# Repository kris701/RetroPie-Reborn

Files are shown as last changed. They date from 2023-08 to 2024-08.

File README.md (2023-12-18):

# RetroPie-Reborn
This is a project to make a handheld console, that can run games from around PlayStation 1 and down.




Its basically a Raspberry Pi 4 that runs on RetroPie. It has small icons that show up in the corner, to give info in things such as how much battery is left or if the Pi is connected to Wifi.
Hardware wise, it has a 7' LCD screen, two small speakers, AUX output, USB-A output and USB-C charging port.
It has two 5000mAh batteries inside of it, giving it ~4 hours of normal usage before running out (but it really depends on what you use it for).
The console also has a little fan, that automatically turns on and off depending on the internal temperature of the Pi.

I originally designed it to include build in controllers on the side, however making the PCBs for the button pads didnt work out.
As a backup, i build in a connector on the two sides of the console, that can be used for future controller additions. 
Each side is basically mirrored, pinout wise, where each side supports up to 11 buttons (or 9 buttons and 2 analog inputs). Each side also have a GND and +5V pin.

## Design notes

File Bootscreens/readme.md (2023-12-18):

# Bootscreens

A custom bootscreen for RetroPie was also made, using Adobe After Effects (the `.aep` file is located here)
There is one thats an entire minute, and one that have been cut to somewhat fit the boot time it took for the Pi i used.

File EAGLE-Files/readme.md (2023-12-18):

# EAGLE Files

I made a bunch of custom PCB components for this project.
In this folder is all the EAGLE sketch and board files for it.
I milled all the boards on my CNC machine.

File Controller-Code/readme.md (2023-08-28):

Based on https://github.com/alexis-boisserand/RetroDeluxe-TeensyController

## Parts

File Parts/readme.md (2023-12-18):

# Parts used

* Raspberry Pi 4B 8GB
* SanDisk Extreme PRo 128GB SD Card
* Micro-HDMI to HDMI: 
* Type-C USB charger board for 2S: 
* 2x 5000mah LiPo Battery: 
* 7-inch LCD Screen: 
* USB Extender: 
* 3.5mm AUX Socket: 
* Raspberry Pi 4B Heatsinks: 
* 2S to 5v, 5A, Step Down: 
* ADS1015: 
* 5v Fan: 
* PAM8403: 
* 8 Ohm Speaker:

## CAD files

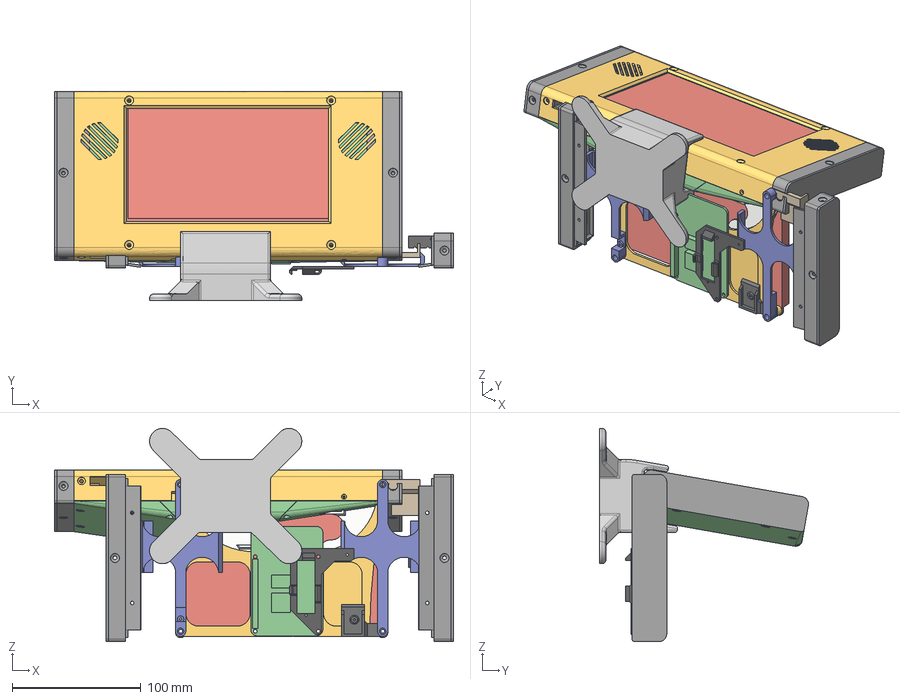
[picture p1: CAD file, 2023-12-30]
3D-Print-Files/Stand.iges
310.0 x 162.4 x 165.6 mm

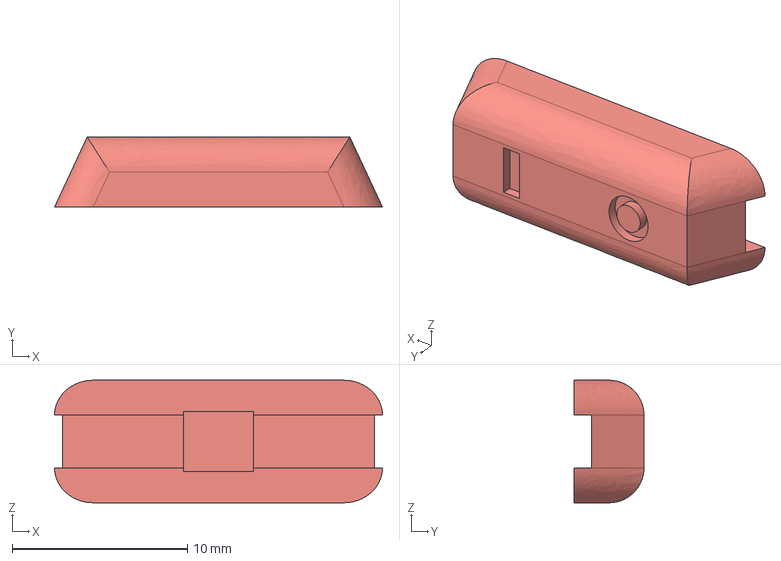
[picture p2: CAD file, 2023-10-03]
3D-Print-Files/SwitchCover.iges
18.7 x 4.00 x 7.00 mm

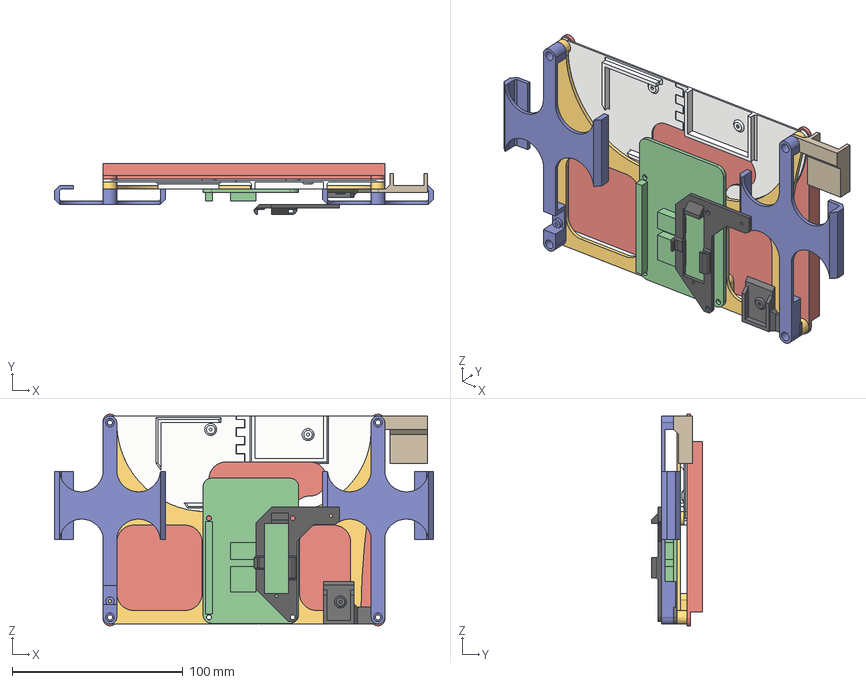
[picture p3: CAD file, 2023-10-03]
3D-Print-Files/Bracket.iges
222.0 x 30.0 x 124.0 mm

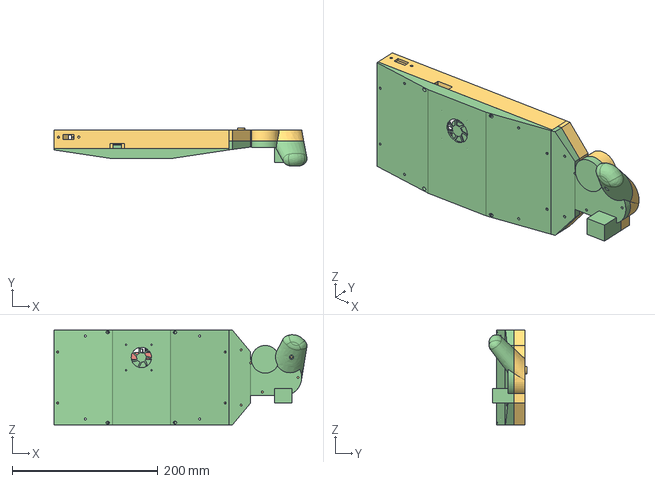
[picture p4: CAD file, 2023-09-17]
3D-Print-Files/Shell.iges
347.3 x 52.0 x 130.0 mm

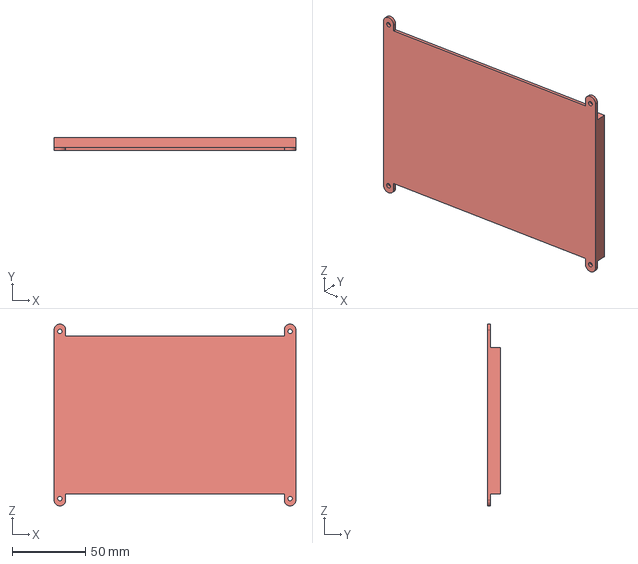
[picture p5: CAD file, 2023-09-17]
3D-Print-Files/Screen.iges
165.0 x 9.00 x 124.0 mm

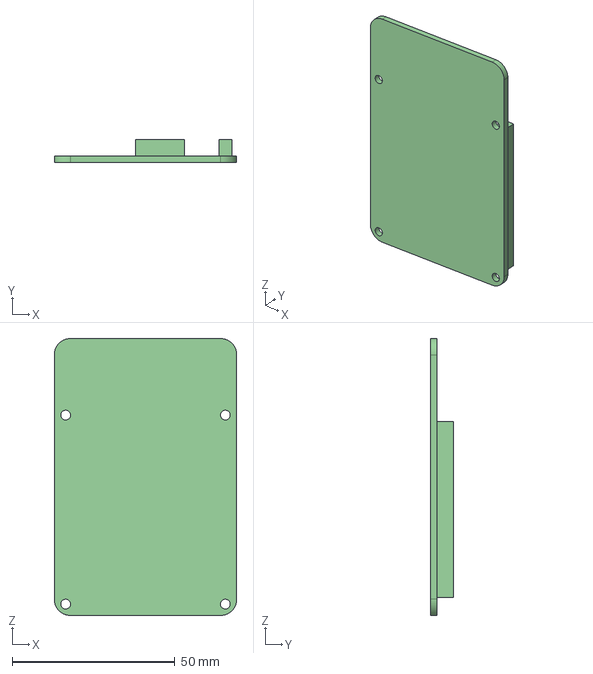
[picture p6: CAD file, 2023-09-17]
3D-Print-Files/Raspberry Pi 4.iges
56.0 x 7.00 x 85.0 mm

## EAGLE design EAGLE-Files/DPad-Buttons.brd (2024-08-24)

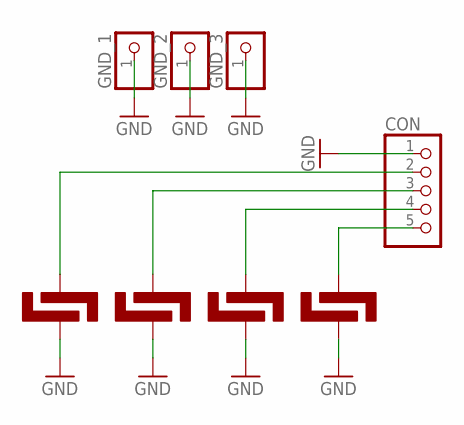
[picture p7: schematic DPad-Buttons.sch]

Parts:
BTN1, BTN2, BTN3, BTN4: BTN_5MM_LONG
CON: PINHD-1X5/90; 1X05/90
GND_1, GND_2, GND_3: PINHD-1X1; 1X01

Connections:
GND: BTN1.P$2, BTN2.P$2, BTN3.P$2, BTN4.P$2, CON.1, GND_1.1, GND_2.1, GND_3.1
unnamed: BTN1.P$1, CON.2
unnamed: BTN4.P$1, CON.5
unnamed: BTN3.P$1, CON.4
unnamed: BTN2.P$1, CON.3

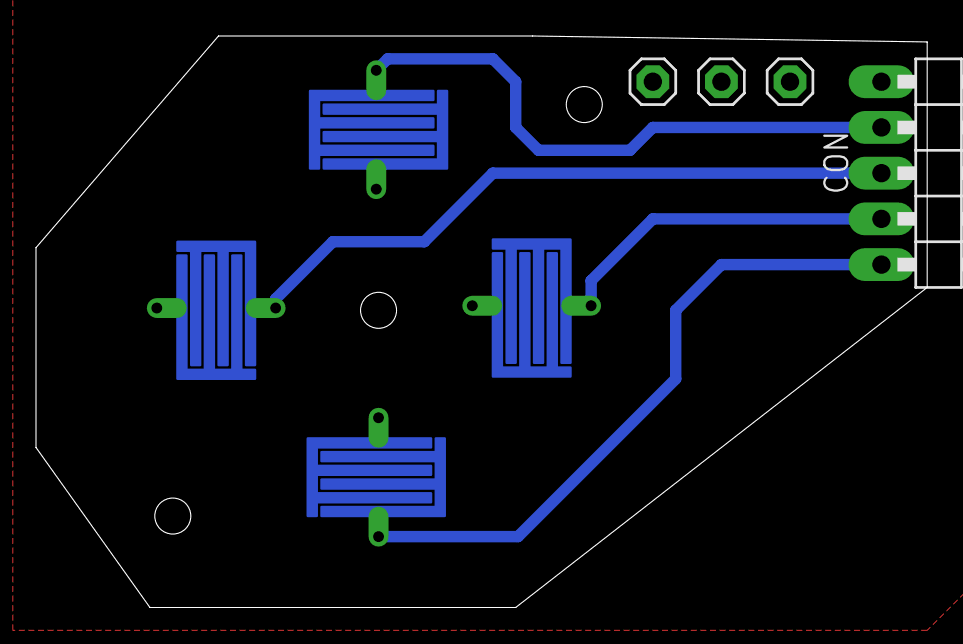
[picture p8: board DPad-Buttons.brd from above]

Board: 2 copper layers, 49.5 x 31.8 mm, 8 parts (0 on the bottom side), 5 nets.

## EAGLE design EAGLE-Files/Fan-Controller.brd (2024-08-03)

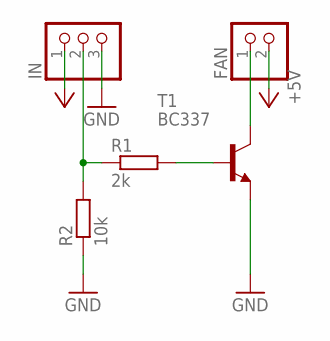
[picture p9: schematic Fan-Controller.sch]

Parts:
FAN: PINHD-1X2/90; 1X02/90
IN: PINHD-1X3/90; 1X03/90
R1: 2k; 0204/7
R2: 10k; 0204/7
T1: BC337; TO92

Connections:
+5V: FAN.2, IN.1
GND: IN.3, R2.1, T1.1 (E)
unnamed: FAN.1, T1.3 (C)
unnamed: R1.2, T1.2 (B)
unnamed: IN.2, R1.1, R2.2

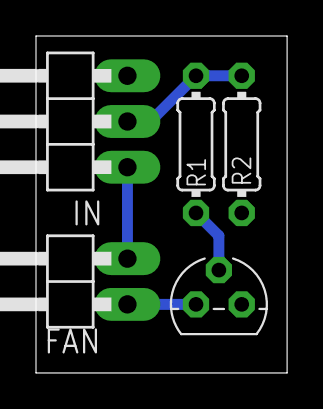
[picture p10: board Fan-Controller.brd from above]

Board: 2 copper layers, 13.9 x 18.7 mm, 5 parts (0 on the bottom side), 5 nets.

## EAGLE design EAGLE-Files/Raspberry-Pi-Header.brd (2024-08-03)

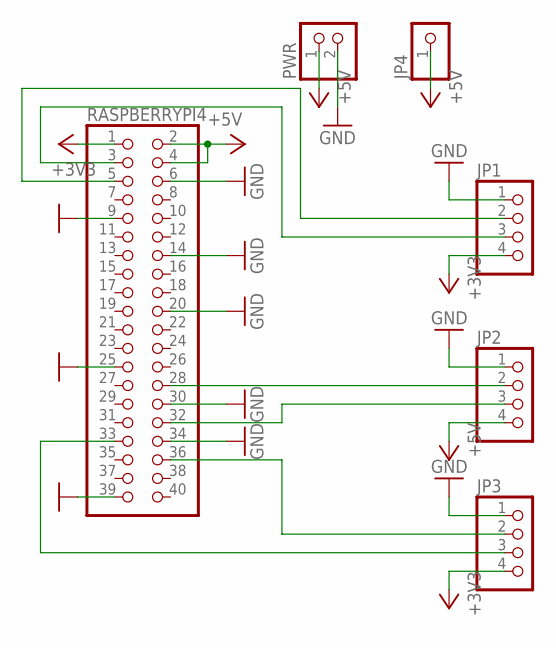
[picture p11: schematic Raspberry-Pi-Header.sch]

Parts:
JP1, JP2, JP3: PINHD-1X4/90; 1X04/90
JP4: PINHD-1X1; 1X01
PWR: PINHD-1X2/90; 1X02/90
RASPBERRYPI4: PINHD-2X20; 2X20

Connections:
+3V3: JP1.4, JP3.4, RASPBERRYPI4.1
+5V: JP2.4, JP4.1, PWR.1, RASPBERRYPI4.2, RASPBERRYPI4.4
GND: JP1.1, JP2.1, JP3.1, PWR.2, RASPBERRYPI4.6, RASPBERRYPI4.9, RASPBERRYPI4.14, RASPBERRYPI4.20, RASPBERRYPI4.25, RASPBERRYPI4.30, RASPBERRYPI4.34, RASPBERRYPI4.39
GPIO1: JP2.2, RASPBERRYPI4.28
GPIO12: JP2.3, RASPBERRYPI4.32
GPIO13: JP3.3, RASPBERRYPI4.33
GPIO16: JP3.2, RASPBERRYPI4.36
SCL: JP1.2, RASPBERRYPI4.5
SDA: JP1.3, RASPBERRYPI4.3

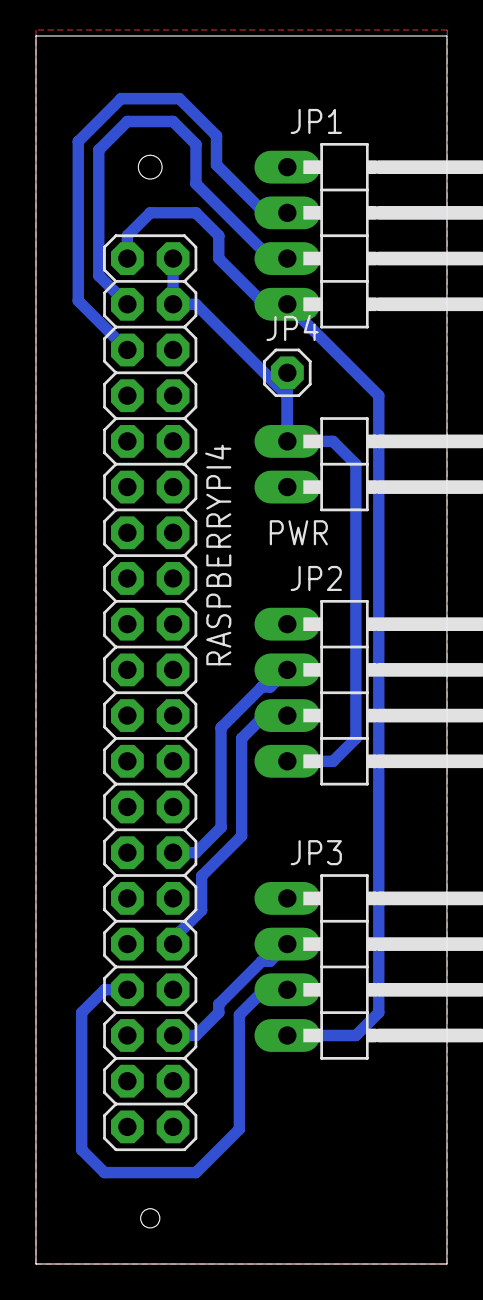
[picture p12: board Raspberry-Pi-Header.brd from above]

Board: 2 copper layers, 22.8 x 68.2 mm, 6 parts (0 on the bottom side), 9 nets.

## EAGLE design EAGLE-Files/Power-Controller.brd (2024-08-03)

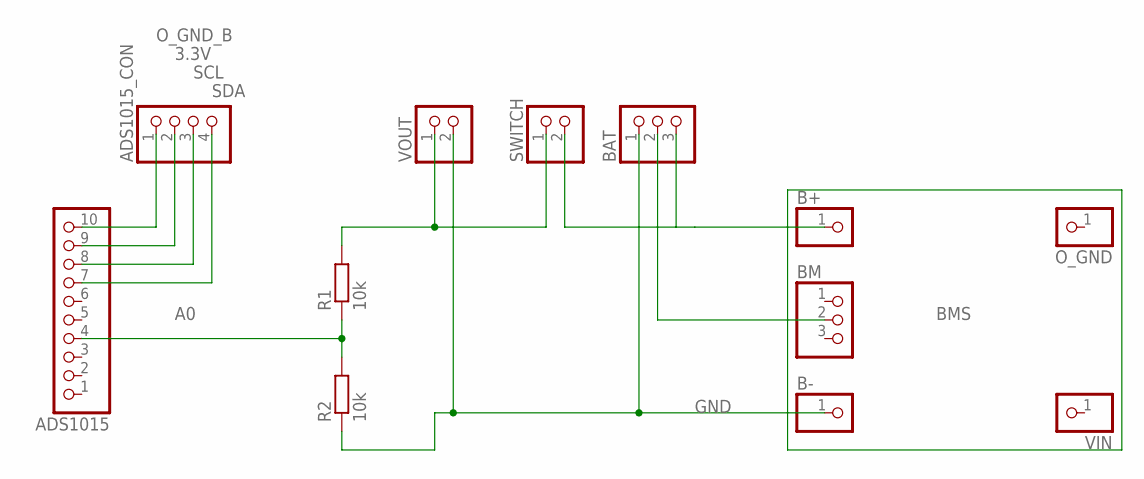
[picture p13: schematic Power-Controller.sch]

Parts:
ADS1015: PINHD-1X10; 1X10
ADS1015_CON: PINHD-1X4/90; 1X04/90
B+: PINHD-1X1; 1X01
B-: PINHD-1X1; 1X01
BAT: PINHD-1X3/90; 1X03/90
BM: PINHD-1X3; 1X03
O_GND: PINHD-1X1; 1X01
R1, R2: 10k; 0204/7
SWITCH: PINHD-1X2; 1X02
VIN: PINHD-1X1; 1X01
VOUT: PINHD-1X2/90; 1X02/90

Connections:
3.3V: ADS1015.9, ADS1015_CON.2
A0: ADS1015.4, R1.1, R2.2
GND: B-.1, BAT.1, R2.1, VOUT.2
unnamed: B+.1, BAT.3, SWITCH.2
unnamed: BAT.2, BM.2
unnamed: R1.2, SWITCH.1, VOUT.1
O_GND_B: ADS1015.10, ADS1015_CON.1
SCL: ADS1015.8, ADS1015_CON.3
SDA: ADS1015.7, ADS1015_CON.4

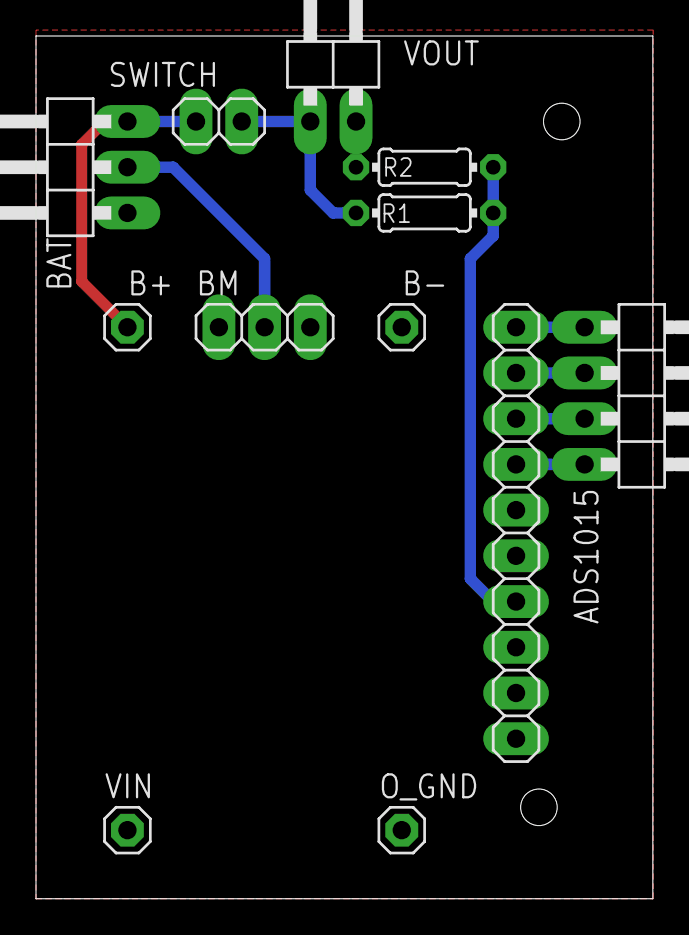
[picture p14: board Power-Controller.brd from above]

Board: 2 copper layers, 34.3 x 47.9 mm, 12 parts (0 on the bottom side), 9 nets.

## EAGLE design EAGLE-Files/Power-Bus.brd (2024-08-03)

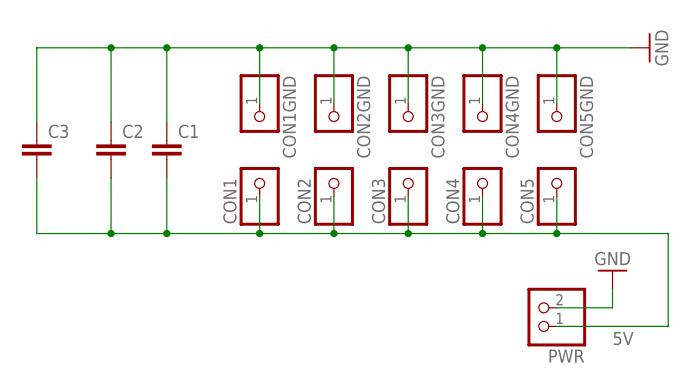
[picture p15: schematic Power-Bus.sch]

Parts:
C1, C2, C3: C-EU050-025X075; C050-025X075
CON1, CON1GND, CON2, CON2GND, CON3, CON3GND, CON4, CON4GND, CON5, CON5GND: PINHD-1X1; 1X01
PWR: PINHD-1X2/90; 1X02/90

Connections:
5V: C1.2, C2.2, C3.2, CON1.1, CON2.1, CON3.1, CON4.1, CON5.1, PWR.1
GND: C1.1, C2.1, C3.1, CON1GND.1, CON2GND.1, CON3GND.1, CON4GND.1, CON5GND.1, PWR.2

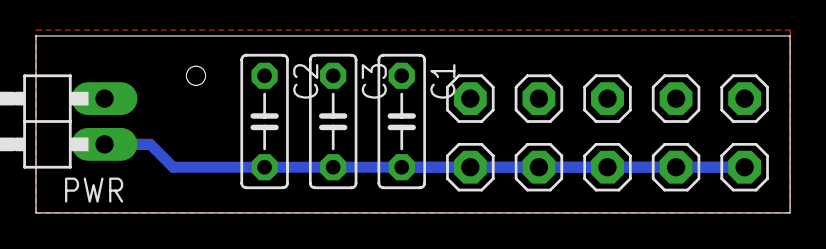
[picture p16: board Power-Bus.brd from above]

Board: 2 copper layers, 41.9 x 9.8 mm, 14 parts (0 on the bottom side), 2 nets.

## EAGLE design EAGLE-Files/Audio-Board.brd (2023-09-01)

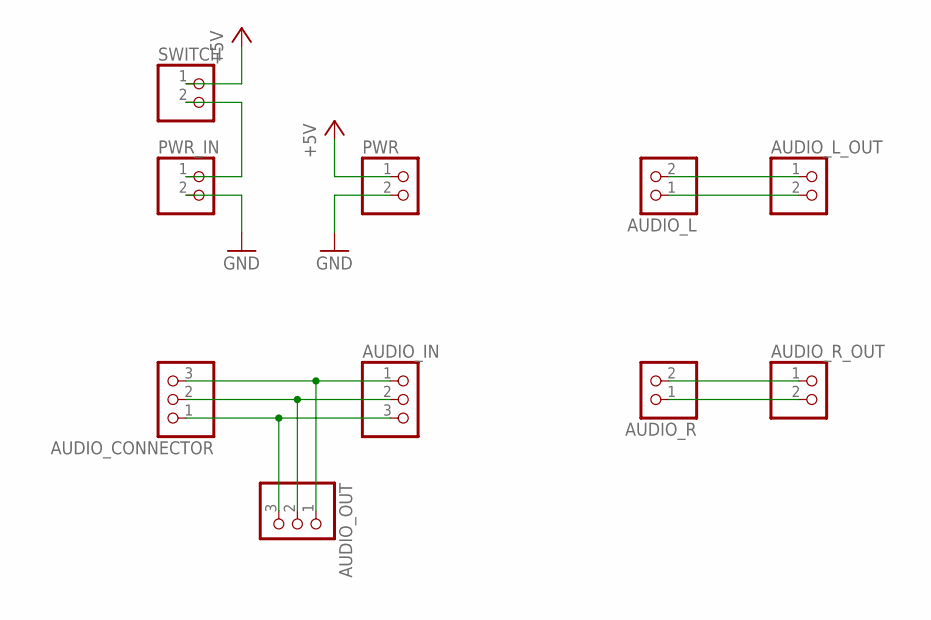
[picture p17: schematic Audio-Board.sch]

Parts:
AUDIO_CONNECTOR: PINHD-1X3; 1X03
AUDIO_IN: PINHD-1X3; 1X03
AUDIO_L: PINHD-1X2; 1X02
AUDIO_L_OUT: PINHD-1X2/90; 1X02/90
AUDIO_OUT: PINHD-1X3; 1X03
AUDIO_R: PINHD-1X2; 1X02
AUDIO_R_OUT: PINHD-1X2/90; 1X02/90
PWR: PINHD-1X2; 1X02
PWR_IN: PINHD-1X2/90; 1X02/90
SWITCH: PINHD-1X2/90; 1X02/90

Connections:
+5V: PWR.1, SWITCH.1
GND: PWR.2, PWR_IN.2
unnamed: AUDIO_CONNECTOR.3, AUDIO_IN.1, AUDIO_OUT.1
unnamed: AUDIO_CONNECTOR.2, AUDIO_IN.2, AUDIO_OUT.2
unnamed: AUDIO_CONNECTOR.1, AUDIO_IN.3, AUDIO_OUT.3
unnamed: AUDIO_L.1, AUDIO_L_OUT.2
unnamed: AUDIO_L.2, AUDIO_L_OUT.1
unnamed: AUDIO_R.2, AUDIO_R_OUT.1
unnamed: AUDIO_R.1, AUDIO_R_OUT.2
unnamed: PWR_IN.1, SWITCH.2

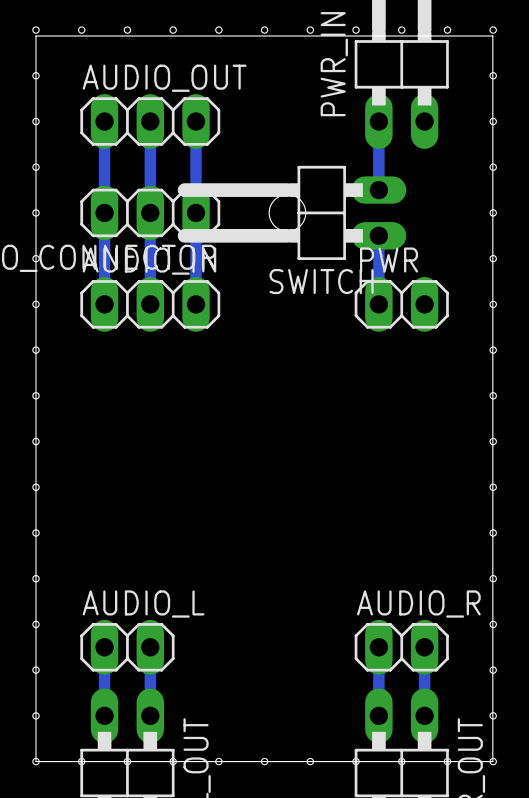
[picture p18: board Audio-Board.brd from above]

Board: 2 copper layers, 25.4 x 40.3 mm, 10 parts (0 on the bottom side), 10 nets.

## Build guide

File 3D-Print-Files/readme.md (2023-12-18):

# 3D Print Files
The entire console is 3D printed, consisting of 2 primary parts:
* The **Bracket**, which is the internal plating holding all the internal components together, and
* the **Shell**, which is the outer shell of the console.

All the parts was drawn in Fusion 360 and exported here as `.iges` files.

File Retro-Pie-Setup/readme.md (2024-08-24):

# Initial Setup
1. Get image the [RetroPie Image](https://retropie.org.uk/download/)
2. Use rofus to write to SD card
3. Ket first boot happen.
4. Go to settings and then retropie settings.
5. Set wifi SSID and password manually
     (wait for a few seconds for it to connect to the wifi)
6. Click on update and let it all update
7. Reboot

# Keyboard Language 
1. F4 to exit emulationstation to the console.
2. Cd all the way to root (i.e. `cd ..`, `cd ..` etc.)
3. Type `sudo nano /etc/default/keyboard` and change the `XKBLAYOUT="gb"` to `XKBLAYOUT="{LANGUAGE}"`
4. Reboot

# Screen Setup
1. F4 to exit emulationstation to the console
2. Cd all the way to root
3. Type `sudo nano /boot/config.txt` and enter the following:
  ```
hdmi_group=2
hdmi_mode=87
hdmi_cvt=1024 600 60 6 0 0 0
hdmi_force_hotplug=1
hdmi_drive=2
```
4. Reboot

# Hide boot code log
1. F4 to exit emulationstation to the console
2. Cd all the way to root
3. Type `sudo nano /boot/cmdline.txt`
4. Do the following:
	a. Replace `console=tty1` with `console=tty3`
	b. Add `loglevel=3`
	c. Add `logo.nologo`
5. Save and exit
6. Type `sudo nano /boot/config.txt`
7. Add `disable_splash=1` at the end of the file
8. Save and exit
9. Reboot

# Add custom bootscreen (Assuming this repo is in home)
1. F4 to exit emulationstation to the console
2. Type `cp RetroPie-Reborn/Bootscreens/bootscreen_short.mp4 RetroPie/splashscreens/video/bootscreen_short.mp4`
3. Go back to the emulationstation
4. Go to settings
5. Go to retropie settings
6. Select a custom splashscreen, being the MP4 file
7. Reboot

# Run the background runner at boot (Assuming this repo is in home)
1. F4 to exit emulationstation to the console
2. Type `crontab -e`
3. Go to the end of the file, and write `@reboot sleep 10 && python3 RetroPie-Reborn/Backround-Runner/Backround_Runner.py`
4. Reboot

# Run rclone every minute (if you have rclone setup)
1. F4 to exit emulationstation to the console
2. Type `crontab -e`
3. Go to the end of the file, and write `* * * * * rclone sync /home/pi/RetroArch remote:"Real Documents/RetroArch"`
4. Reboot

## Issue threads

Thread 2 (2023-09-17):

Test fan controller board

kris701, 2023-09-17:

kris701, 2023-11-13:
Flip the transistor!
Looks like I turned it the wrong way

Closed 2023-11-14.

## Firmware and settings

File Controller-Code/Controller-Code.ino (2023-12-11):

#include <Bounce.h>
#include "defaultController.h"

#define ARRAY_SIZE(a) (sizeof(a) / sizeof(a[0]))
const int buttonsMapSize = ARRAY_SIZE(buttonsMap);
const int dpadButtonsSize = ARRAY_SIZE(dpadMap);
Bounce* buttons[buttonsMapSize];
Bounce* dpadButtons[dpadButtonsSize];

void setup() {
    Joystick.useManualSend(true);

    for (int i = 0; i < buttonsMapSize; ++i) {
        const uint8_t pin = buttonsMap[i][0];
        buttons[i] = new Bounce(pin, 10);
        pinMode(pin, INPUT_PULLUP);
    }
    for (int i = 0; i < dpadButtonsSize; ++i) {
        const uint8_t pin = dpadMap[i];
        dpadButtons[i] = new Bounce(pin, 10);
        pinMode(pin, INPUT_PULLUP);
    }
}

void loop() {
    handleAnalog();
    handleButtons();
    Joystick.hat(handleDpad());
    Joystick.send_now();
    delay(50);
}

void handleAnalog() {
    // read 6 analog inputs and use them for the joystick axis
    Joystick.X(analogRead(axisXPlus));
    // we need to invert the y axis
    Joystick.Y(1023 - analogRead(axisXMinus));
    Joystick.Z(analogRead(axisYPlus));
    Joystick.Zrotate(analogRead(axisYMinus));
}

void handleButtons() {
    // read digital pins and use them for the buttons
    for (int i = 0; i < buttonsMapSize; ++i) {
        const uint8_t* buttonMapping = buttonsMap[i];
        buttons[i]->update();

        if (buttons[i]->fallingEdge()) {
            Joystick.button(buttonMapping[1], 1);
        }

        if (buttons[i]->risingEdge()) {
            Joystick.button(buttonMapping[1], 0);
        }
    }
}

int handleDpad() {
    uint8_t dpadValue = 0;
    for (int i = 0; i < dpadButtonsSize; ++i) {
        dpadButtons[i]->update();
        int value = 0;
        if (dpadButtons[i]->fallingEdge())
            value = 1;
        dpadValue |= value << i;
    }

    int angle = 0;
    switch (dpadValue) {
    case 0x0:
        // no button pressed, return to the rest position
        angle = -1;
        break;
    case 0x1:
        angle = 0;
        break;
    case 0x2:
        angle = 90;
        break;
    case 0x3:
        angle = 45;
        break;
    case 0x4:
        angle = 180;
        break;
    case 0x6:
        angle = 135;
        break;
    case 0x8:
        angle = 270;
        break;
    case 0xC:
        angle = 225;
        break;
    case 0x9:
        angle = 315;
        break;
    }
    return angle;
}

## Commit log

2023-08-28 Added config info
    [misc retropie configuration setups.txt]
2023-08-28 Added initial EAGLE files
    [DPad-Buttons.brd, DPad-Buttons.sch, Fan-Controller.brd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]
2023-08-29 * Updated gitignore * Updated some of the EAGLE boards
    [Power-Bus.brd, Raspberry-Pi-Header.brd]
2023-08-29 * Updated gitignore * Updated some boards and schematics
    [Fan-Controller.brd, Fan-Controller.sch, Power-Bus.brd]
2023-08-29 Fixed a board
    [Raspberry-Pi-Header.brd]
2023-09-01 * Updated the header board * Added a audio board * Added a power controller board * Updated gitignore
    [Audio-Board.brd, Audio-Board.sch, Power-Controller.brd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]
2023-09-03 * Fixed a small error in the Raspberry Pi GPIO Header board (pins was offset) * Added the initial 3d print files
    [InnerBracket.f3d, Raspberry-Pi-Header.brd, Raspberry-Pi-Header.sch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]
2023-09-07 Updated the 3D Print files * The inner bracket is finished * The outer shell is updated (WIP)
    [InnerBracket.f3d, Shell.f3d]
2023-09-07 Initial implementation of the battery icon runner
2023-09-08 * Indexed all the battery icons * Added a Fan Icon Runner to control the fan * Updated icons
2023-09-12 Updated the 3d models
    [InnerBracket.iges, Shell.iges]
2023-09-17 Updated design files
    [Bracket.iges, InnerBracket.f3d, InnerBracket.iges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]
2023-09-23 Updated board layout
    [DPad-Buttons.brd, Four-Buttons.brd]
2023-09-24 Updated boards and 3d models
    [Bracket.iges, DPad-Buttons.brd, Four-Buttons.brd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]
2023-09-25 Updated board layouts
    [DPad-Buttons.brd, DPad-Buttons.sch, Four-Buttons.brd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]
2023-10-03 Updated boards and models
    [Bracket.iges, DPad-Buttons.brd, SwitchCover.iges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]
2023-11-12 Updated the teensy code to fully work with the controller
2023-11-12 Fixed bad timer
2023-11-12 New implementation of the ADC
2023-11-12 More "reasonable" charge voltage values
2023-11-12 Initial pwm setup
2023-11-13 Fixed pin
2023-11-13 New fan icons
2023-11-14 average battery level
2023-11-14 Reduced the battery map
2023-11-14 Updated fan speeds
2023-11-14 Updated fan levels
2023-11-15 Calibrated battery meter
2023-12-17 Tweaked the battery icon runner
2023-12-18 Removed a bunch of old files
    [DPad-Buttons.brd, DPad-Buttons.sch, Four-Buttons.brd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]
2023-12-18 Battery tweaks
2023-12-19 Calibrated battery
2023-12-19 Uses average CPU temp instead of directly the current one
2023-12-19 Set the fan to turn on at higher temps
2023-12-30 Added stand iges
    [Stand.iges]
2024-08-03 Updated all boards for JLCPCB order
    Also added the controller boards and schematics back
    [Audio-Board.sch, DPad-Buttons.brd, DPad-Buttons.sch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]
2024-08-24 Updated the DPad and Four Buttons PCB designs for production
    [DPad-Buttons.brd, DPad-Buttons.sch, Four-Buttons.brd]
